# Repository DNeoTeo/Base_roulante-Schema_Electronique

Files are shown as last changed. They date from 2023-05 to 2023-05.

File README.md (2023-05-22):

# Base_roulante-Schema_Electronique

## Introduction

Dans le cadre du module Challenge, j’ai choisi de participer à la compétition de la coupe de France de Robotique 2023. Ce défi n’est pas envisageable tout seul. Avec des membres de l’association DTRE nous avons décidé de former une équipe. Ce « hackathon » nous a amené le défi de gérer et d’organiser une équipe de 29 personnes. À travers ce projet, j’ai pu travailler sur les différentes thématiques techniques telles que la programmation orienté objet, la mécanique ou encore l’électronique.

L’évènement a débuté le 10 septembre 2022 lors de la conférence de présentation de Planète Science organisé sur le campus d’EPITA. Ils y ont délivré la première version du règlement qui fut mis à jour quelques mois plus tard pour des questions d’homogénéités et pour clarifier certains points déséquilibré remontées par les équipes. Ce première évènement en début d’année nous a permis de poser toutes nos questions aux organisateurs et aux équipes vétéranes. Puisque nous sommes tous totalement novice de cette compétition. Le thème de cette année étant « The Cherry on the cake » pour fêter les 30 ans d’Eurobot, Planète Science demande aux équipes participant à la coupe de France de robotique de « cuisiner pour faire la fête ». 
Les missions fixées par le règlement de la 30ème édition sont : 

  − Fabriquer des gâteaux − Positionner la cerise sur les gâteaux   
  − Ranger le surplus des cerises dans le panier   
  − Se déguiser pour faire la fête. 
  
Sur le campus d’EPITA nous avons rencontré les organisateurs et des équipes habitués auprès desquelles nous avons pu prendre de précieux conseils.

Au début, Yasin, un membre de la DTRE et moi-même avons beaucoup travaillé en duo pour démarrer le projet puis nous avons délégué certaines parties aux membres qui ont rejoint l’équipe. J’ai ainsi participé à : 
  - Tous les entretiens des membres de l’équipe, 
  - La définition du budget (Annexe – Budget), 
  - La demande de subvention auprès de l’école ([Lien](https://docs.google.com/presentation/d/1tvP93IFA4L__9xUBjh1RfveQjmiez2jK/edit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)), 
  - Relecture du rapport PST de mi-année ([Lien](https://etesiea.sharepoint.com/:w:/r/sites/LesCavistes/Shared%20Documents/Rapport-PST/Rapport_PST_CDF_de_Robotique_2023.docx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)), 
  - Discussion avec les différents pôles pour connaître leur stratégie, 
  - Suivi de certains groupes pour s’assurer qu’ils n’avaient pas de problème à avancer, 
  - Récupération d’archive auprès d’une ancienne équipe ([Lien](https://etesiea.sharepoint.com/sites/LesCavistes/Shared%20Documents/Forms/AllItems.aspx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)) 
 
En plus de cette partie organisationnelle, je suis dans le pôle Base roulante spécialité électronique. J’ai ainsi réalisé plein de recherche pour le choix des composants de la base roulantes. 
Toutes les recherches sont dans le NoteBook suivant : [Elec – Base roulante](https://etesiea.sharepoint.com/:o:/r/sites/LesCavistes/_layouts/15/Doc.aspx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(Notes%20de%20R%C3%A9union%2FElec%20-%20Notes%20de%20r%C3%A9unions.one%7Cb93d645d-10fc-47ad-a43a-4c280d625987%2FElec%20%E2%80%93%20Base%20roulante%7Cc344ee84-79c5-4be7-819a-d46dd6609212%2F)&wdorigin=703&wdpreservelink=1) ([Web view](https://etesiea.sharepoint.com/:o:/r/sites/LesCavistes/_layouts/15/Doc.aspx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(Notes%20de%20R%C3%A9union%2FElec%20-%20Notes%20de%20r%C3%A9unions.one%7Cb93d645d-10fc-47ad-a43a-4c280d625987%2FElec%20%E2%80%93%20Base%20roulante%7Cc344ee84-79c5-4be7-819a-d46dd6609212%2F)&wdorigin=703&wdpreservelink=1)) Ce notebook est divisé en deux parties, à gauche la liste des composants adéquats pour toute la base roulante et ceux acheté pour le prototype n°1. Et à droite différentes parties théoriques et pistes de recherches pour bien choisir les composants. J’ai réalisé une chaîne fonctionnelle permet de visualiser l’ensemble de notre système : prise de décision avec la chaîne d’information, distribution de l’alimentation avec la chaîne d’énergie. On voit ainsi les composants nécessaires en fonction de leur rôle dans les 2 chaînes. Le diagramme électronique illustre la manière dont nos composants vont être reliés entre eux.

### La chaîne fonctionnelle



### Diagramme électrique



Premier prototype de la base roulante : https://drive.google.com/file/d/1hqDrjrIA7VDXRb-9ib1nsVt9VAf5gUXD/view?usp=share_link

En même que de mettre sur pieds, le prototype, j’ai commencé à faire les bibliothèques de composant sur eagle ainsi que les circuits imprimés. 

### Emergency_button (Board, Schematics et Librairy)







### Entrainement sur EAGLE

J’ai ainsi appris à créer des PCBs sur EAGLE avec la création de librairies ce qui inclut la création de schématics et de boards. Cette entrainement m’a permis de me familiariser avec les librairies de composants et l’IDE d’EAGLE.




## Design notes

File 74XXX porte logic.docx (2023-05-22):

74XXX porte logic

Sparkfun
Power symbol

Wurth

Con -> connectique

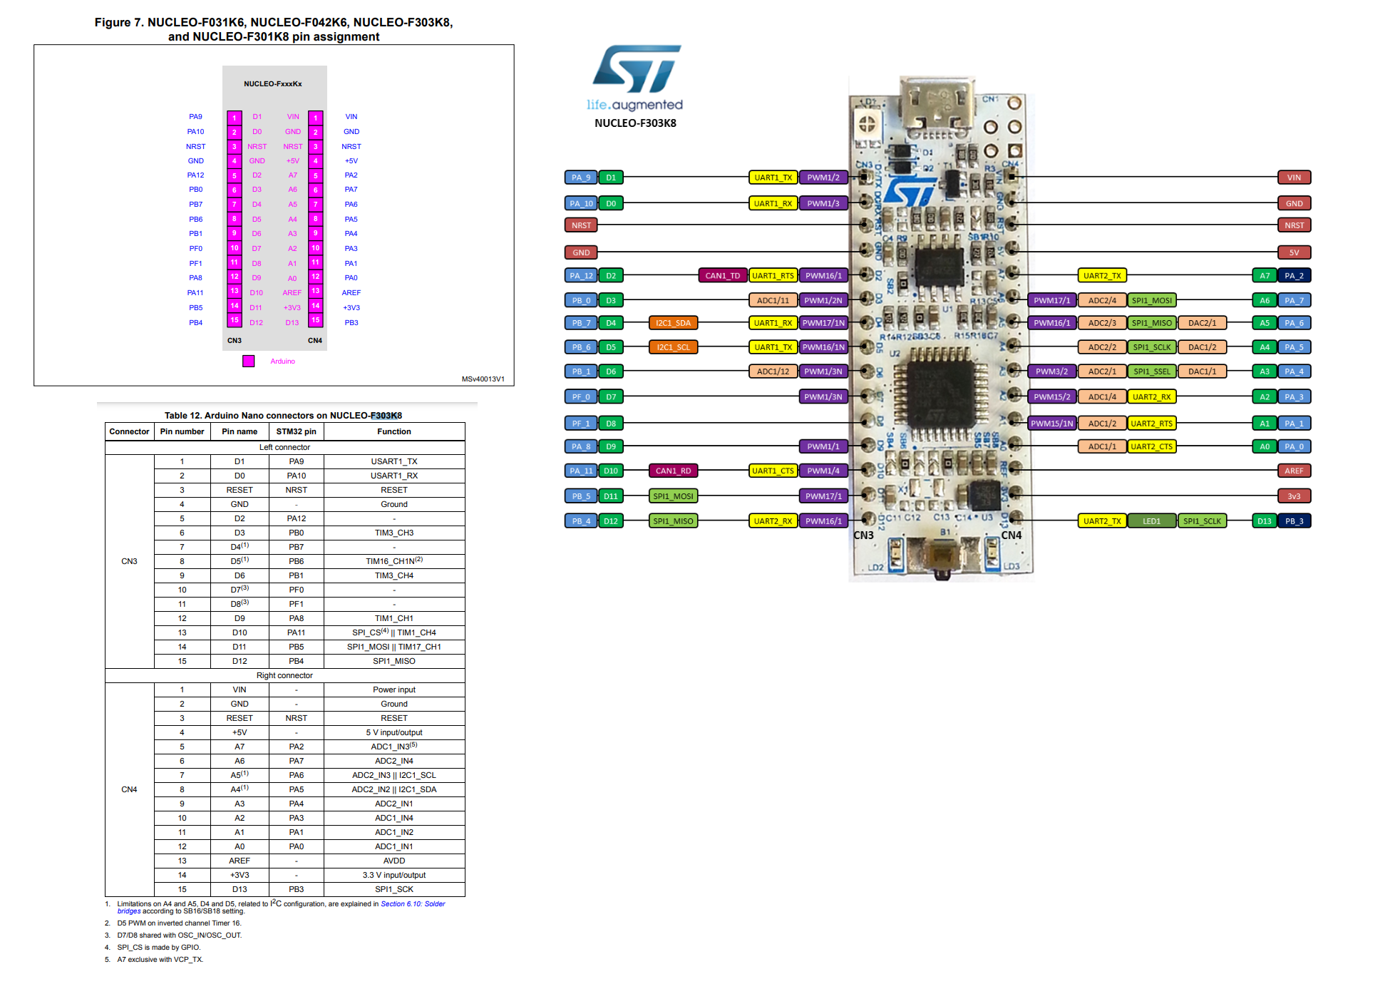
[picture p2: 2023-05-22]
PinMapping NUCLEO-F303K8.png

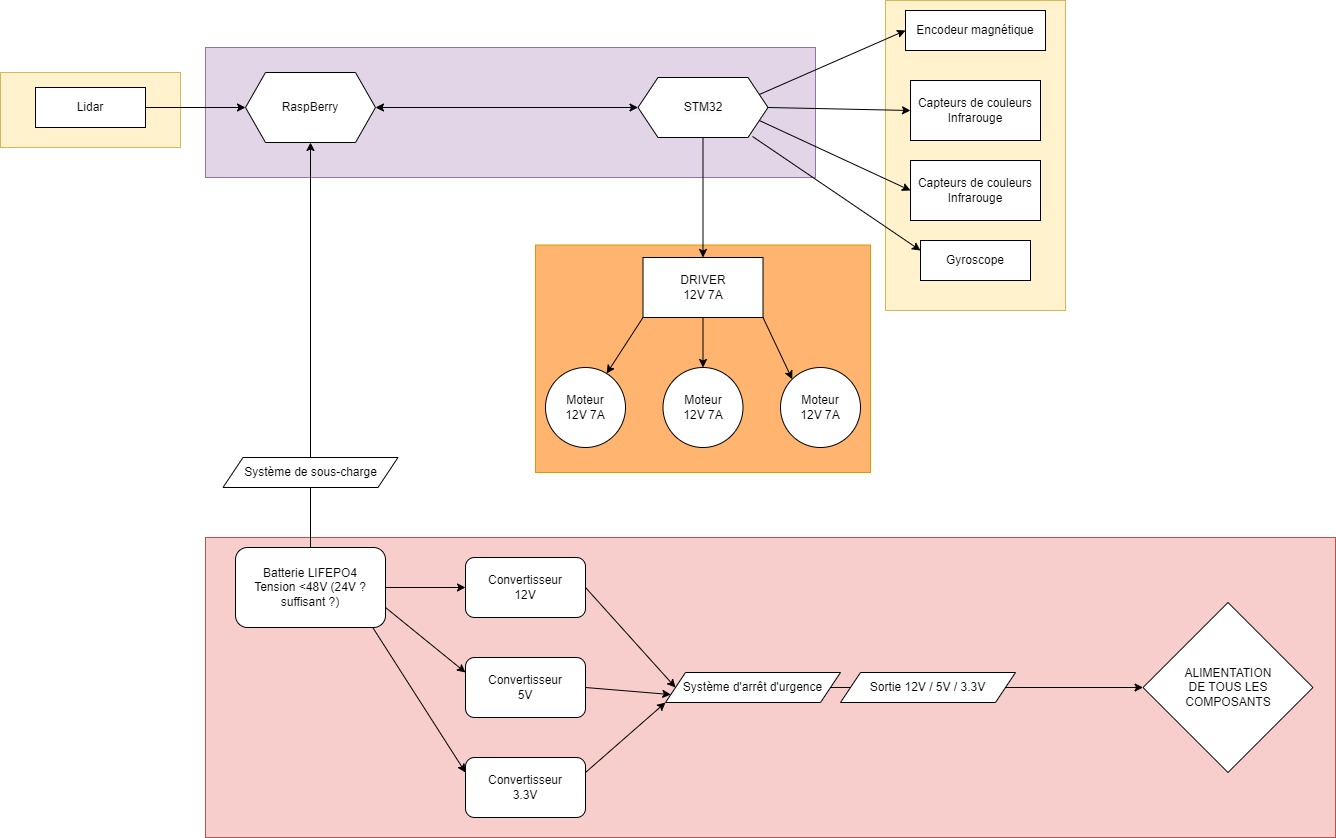
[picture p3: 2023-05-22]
Diagramme electrique.jpg

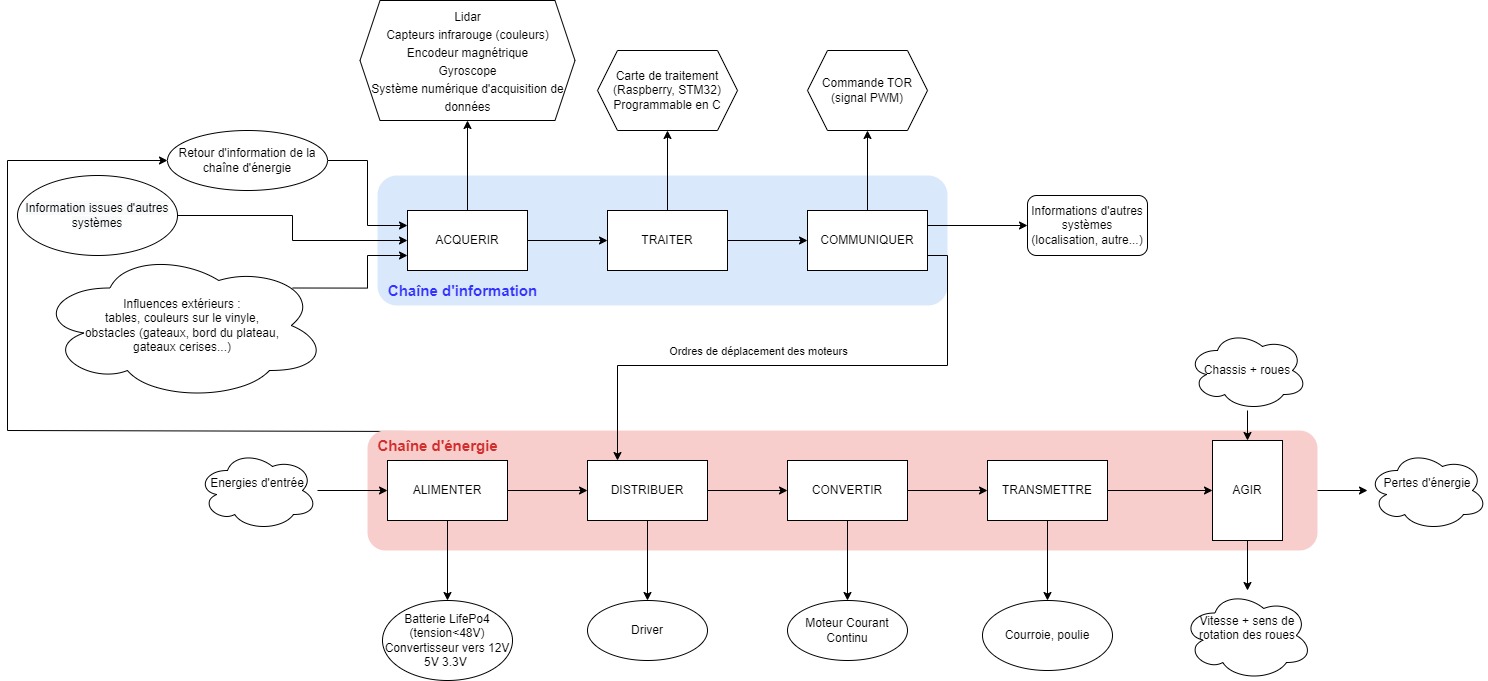
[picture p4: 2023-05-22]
Chaine fonct_energ.jpg

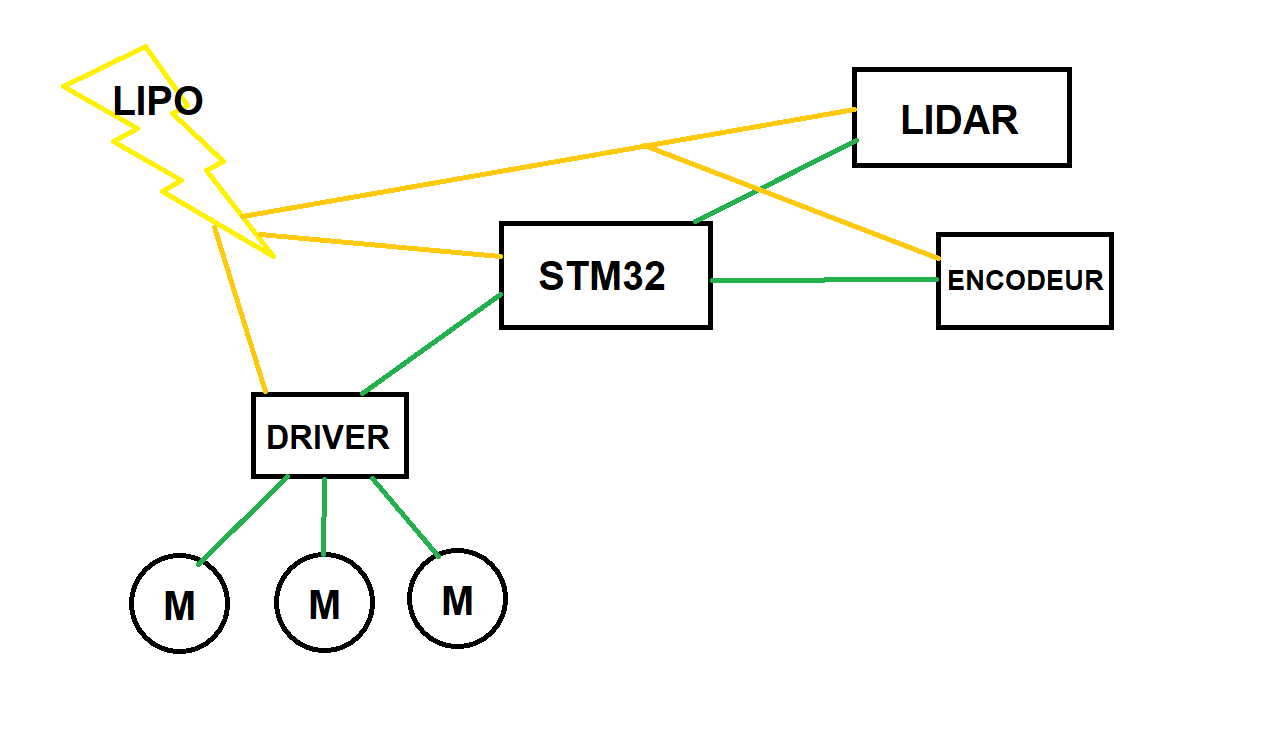
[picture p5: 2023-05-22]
Croquis Schema Elec Base roulante.png

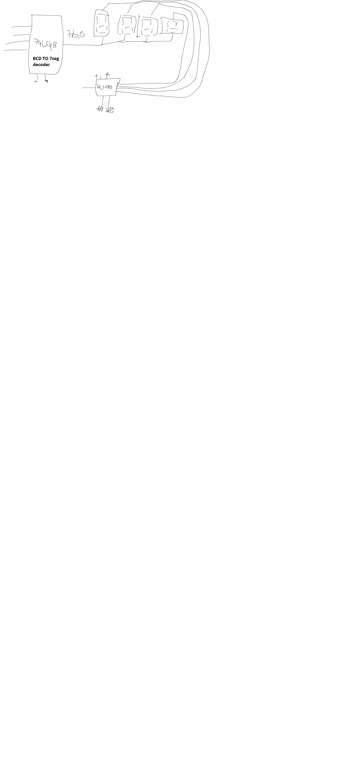
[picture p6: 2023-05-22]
projects/Eagle_train/horloge.png

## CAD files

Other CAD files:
22mm E-Stop v2.f3d

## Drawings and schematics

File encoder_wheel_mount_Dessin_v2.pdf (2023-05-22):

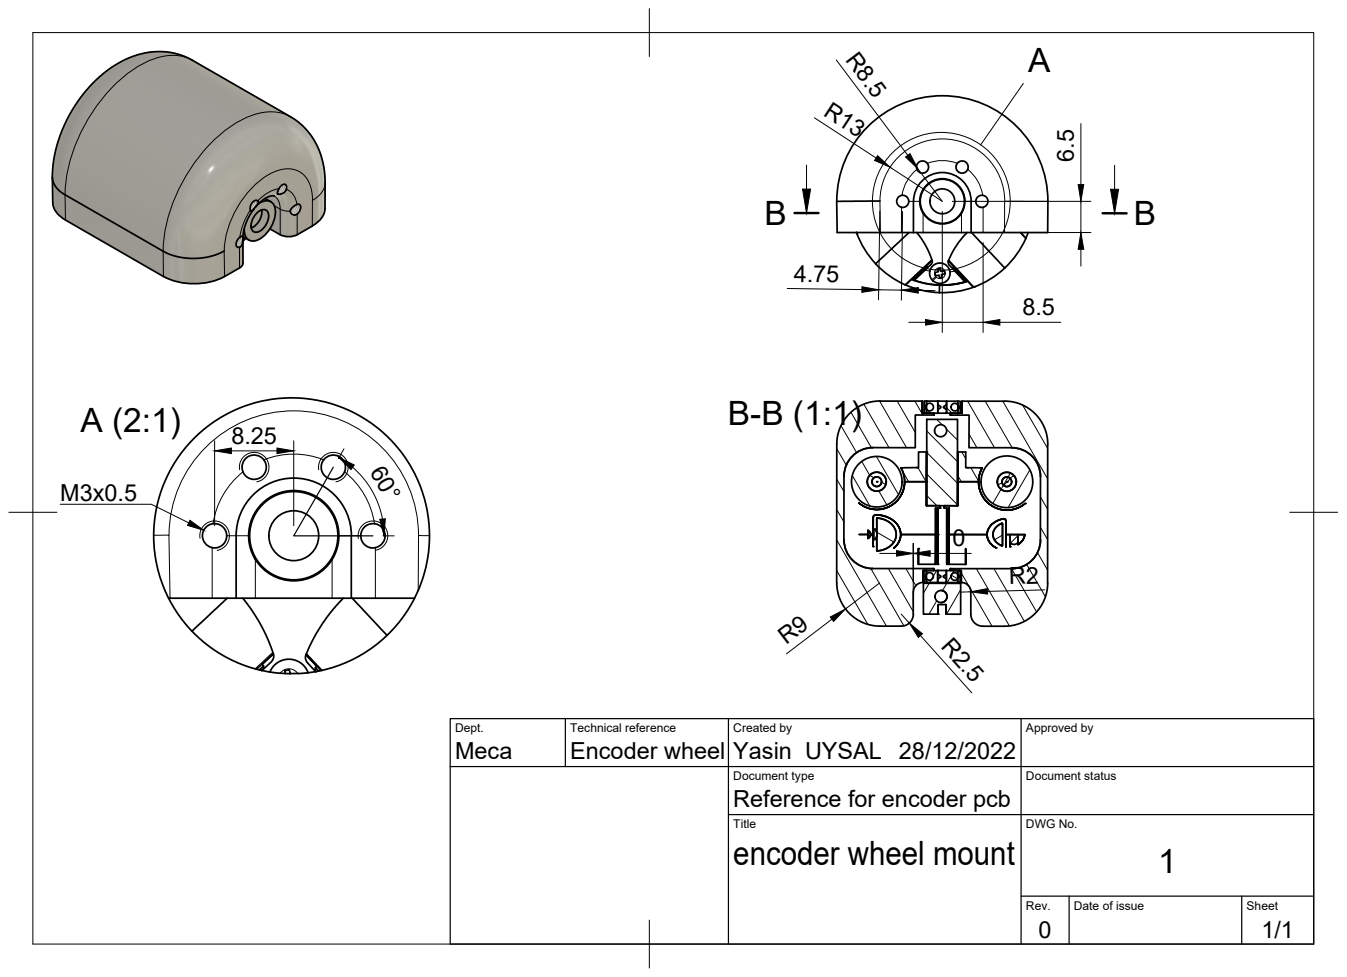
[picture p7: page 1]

Dept. Meca | Technical reference Encoder wheel | Created by Yasin UYSAL 28/12/2022 | Approved by

Document type Reference for encoder pcb | Document status

Title encoder wheel mount | DWG No. 1

Rev. 0 | Date of issue | Sheet 1/1

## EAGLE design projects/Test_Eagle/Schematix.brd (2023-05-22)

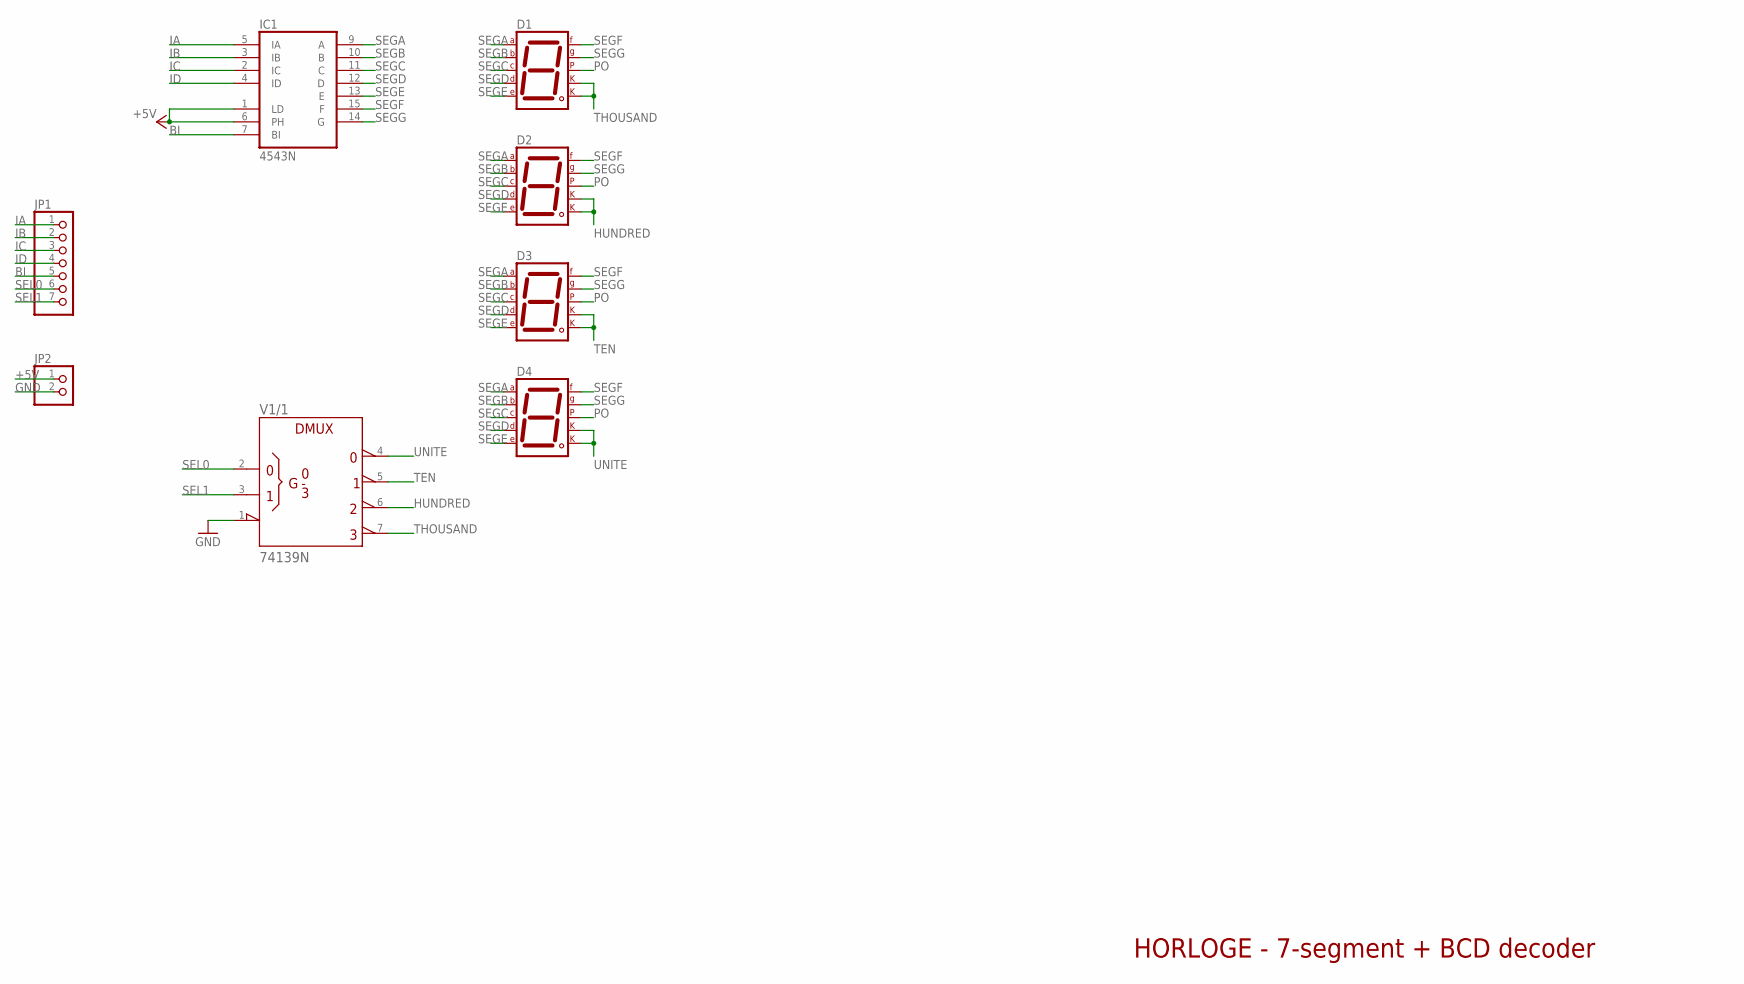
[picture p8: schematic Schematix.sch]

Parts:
D1, D2, D3, D4: 7SEG-CK; 7SEG-13
IC1: 4543N; DIL16
JP1: PINHD-1X7/90; 1X07/90
JP2: PINHD-1X2/90; 1X02/90
V1: 74139N; DIL16

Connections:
+5V: IC1.1 (LD), IC1.6 (PH), JP2.1
+UB: V1.16 (+UB)
-UB: V1.8 (-UB)
BI: IC1.7 (BI), JP1.5
GND: JP2.2, V1.1 (!G)
HUNDRED: D2.3 (CK1), D2.8 (CK2), V1.6 (Y2)
IA: IC1.5 (IA), JP1.1
IB: IC1.3 (IB), JP1.2
IC: IC1.2 (IC), JP1.3
ID: IC1.4 (ID), JP1.4
PO: D1.5 (DP), D2.5 (DP), D3.5 (DP), D4.5 (DP)
SEGA: D1.7 (A), D2.7 (A), D3.7 (A), D4.7 (A), IC1.9 (A)
SEGB: D1.6 (B), D2.6 (B), D3.6 (B), D4.6 (B), IC1.10 (B)
SEGC: D1.4 (C), D2.4 (C), D3.4 (C), D4.4 (C), IC1.11 (C)
SEGD: D1.2 (D), D2.2 (D), D3.2 (D), D4.2 (D), IC1.12 (D)
SEGE: D1.1 (E), D2.1 (E), D3.1 (E), D4.1 (E), IC1.13 (E)
SEGF: D1.9 (F), D2.9 (F), D3.9 (F), D4.9 (F), IC1.15 (F)
SEGG: D1.10 (G), D2.10 (G), D3.10 (G), D4.10 (G), IC1.14 (G)
SEL0: JP1.6, V1.2 (A)
SEL1: JP1.7, V1.3 (B)
TEN: D3.3 (CK1), D3.8 (CK2), V1.5 (Y1)
THOUSAND: D1.3 (CK1), D1.8 (CK2), V1.7 (Y3)
UNITE: D4.3 (CK1), D4.8 (CK2), V1.4 (Y0)
VDD: IC1.16 (VDD)
VSS: IC1.8 (VSS)

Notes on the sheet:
HORLOGE - 7-segment + BCD decoder

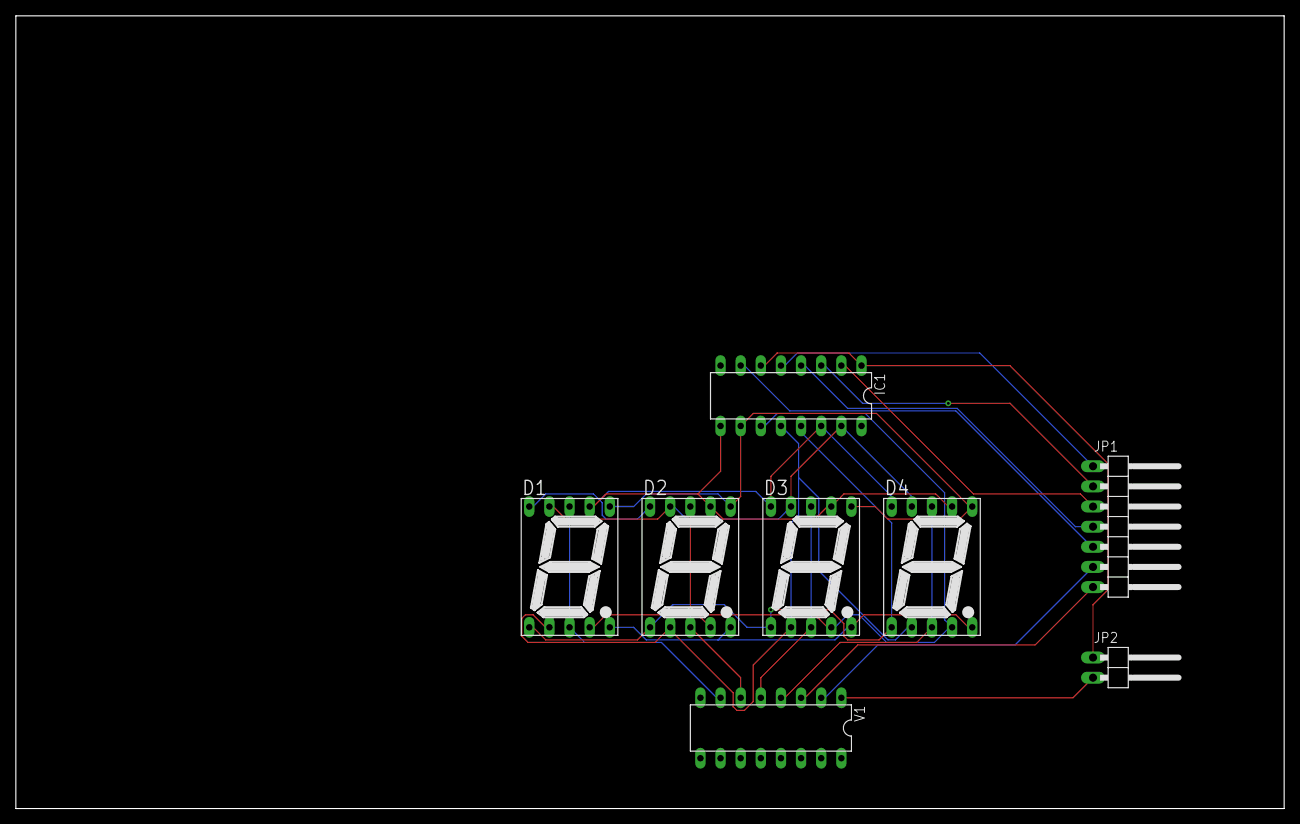
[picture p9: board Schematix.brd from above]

Board: 2 copper layers, 160.0 x 100.0 mm, 8 parts (0 on the bottom side), 21 nets.

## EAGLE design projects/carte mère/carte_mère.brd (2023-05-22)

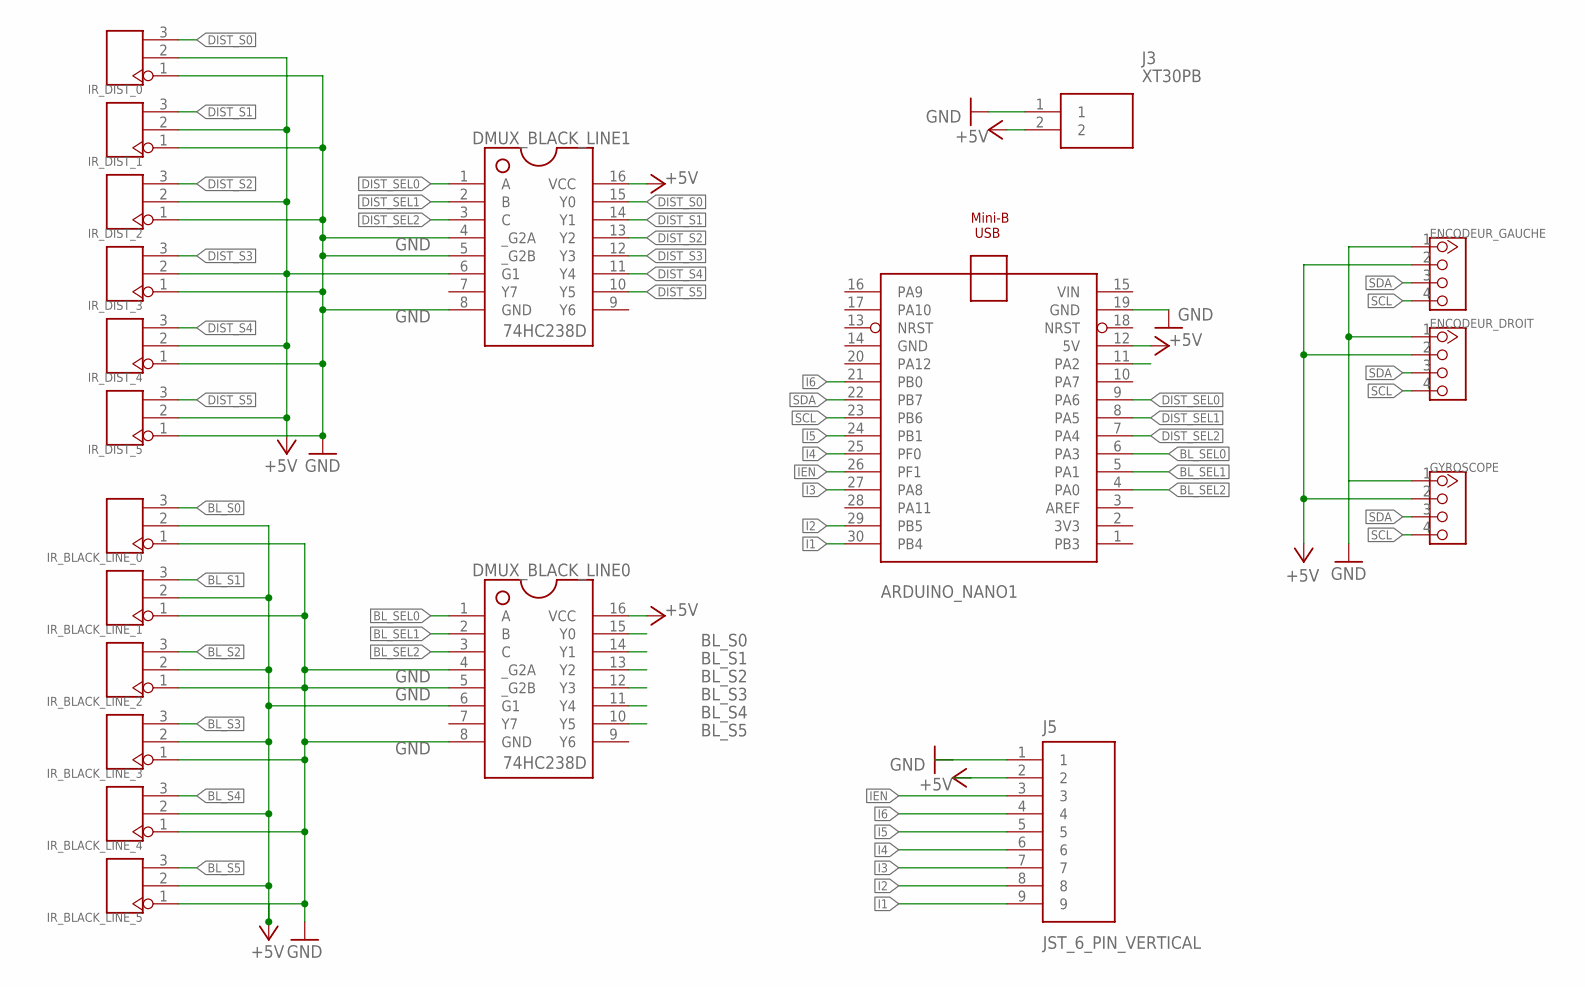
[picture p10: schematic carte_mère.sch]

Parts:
ARDUINO_NANO1: NUCLEO_F303K8
DMUX_BLACK_LINE0, DMUX_BLACK_LINE1: 74HC238D; SOIC127P600X175-16N
ENCODEUR_DROIT: TWIG-4P-2.0'90D'; 4P-2.0-90D
ENCODEUR_GAUCHE: TWIG-4P-2.0'90D'; 4P-2.0-90D
GYROSCOPE: TWIG-4P-2.0'90D'; 4P-2.0-90D
IR_BLACK_LINE_0, IR_BLACK_LINE_1, IR_BLACK_LINE_2, IR_BLACK_LINE_3, IR_BLACK_LINE_4, IR_BLACK_LINE_5: HEADER-3P-2.54; 3P-2.54
IR_DIST_0, IR_DIST_1, IR_DIST_2, IR_DIST_3, IR_DIST_4, IR_DIST_5: HEADER-3P-2.54; 3P-2.54
J3: XT30PB
J5: JST_6_PIN_VERTICAL; JST-6-SMD-VERT-1.0MM

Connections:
+5V: ARDUINO_NANO1.12 (5V), DMUX_BLACK_LINE0.6 (G1), DMUX_BLACK_LINE0.16 (VCC), DMUX_BLACK_LINE1.6 (G1), DMUX_BLACK_LINE1.16 (VCC), ENCODEUR_DROIT.2, ENCODEUR_GAUCHE.2, GYROSCOPE.2, IR_BLACK_LINE_0.2, IR_BLACK_LINE_1.2, IR_BLACK_LINE_2.2, IR_BLACK_LINE_3.2, IR_BLACK_LINE_4.2, IR_BLACK_LINE_5.2, IR_DIST_0.2, IR_DIST_1.2, IR_DIST_2.2, IR_DIST_3.2, IR_DIST_4.2, IR_DIST_5.2, J3.2, J5.2
BL_S0: DMUX_BLACK_LINE0.15 (Y0), IR_BLACK_LINE_0.3
BL_S1: DMUX_BLACK_LINE0.14 (Y1), IR_BLACK_LINE_1.3
BL_S2: DMUX_BLACK_LINE0.13 (Y2), IR_BLACK_LINE_2.3
BL_S3: DMUX_BLACK_LINE0.12 (Y3), IR_BLACK_LINE_3.3
BL_S4: DMUX_BLACK_LINE0.11 (Y4), IR_BLACK_LINE_4.3
BL_S5: DMUX_BLACK_LINE0.10 (Y5), IR_BLACK_LINE_5.3
BL_SEL0: ARDUINO_NANO1.6 (PA3), DMUX_BLACK_LINE0.1 (A)
BL_SEL1: ARDUINO_NANO1.5 (PA1), DMUX_BLACK_LINE0.2 (B)
BL_SEL2: ARDUINO_NANO1.4 (PA0), DMUX_BLACK_LINE0.3 (C)
DIST_S0: DMUX_BLACK_LINE1.15 (Y0), IR_DIST_0.3
DIST_S1: DMUX_BLACK_LINE1.14 (Y1), IR_DIST_1.3
DIST_S2: DMUX_BLACK_LINE1.13 (Y2), IR_DIST_2.3
DIST_S3: DMUX_BLACK_LINE1.12 (Y3), IR_DIST_3.3
DIST_S4: DMUX_BLACK_LINE1.11 (Y4), IR_DIST_4.3
DIST_S5: DMUX_BLACK_LINE1.10 (Y5), IR_DIST_5.3
DIST_SEL0: ARDUINO_NANO1.9 (PA6), DMUX_BLACK_LINE1.1 (A)
DIST_SEL1: ARDUINO_NANO1.8 (PA5), DMUX_BLACK_LINE1.2 (B)
DIST_SEL2: ARDUINO_NANO1.7 (PA4), DMUX_BLACK_LINE1.3 (C)
GND: ARDUINO_NANO1.14 (GND), ARDUINO_NANO1.19 (GND), DMUX_BLACK_LINE0.4 (_G2A), DMUX_BLACK_LINE0.5 (_G2B), DMUX_BLACK_LINE0.8 (GND), DMUX_BLACK_LINE1.4 (_G2A), DMUX_BLACK_LINE1.5 (_G2B), DMUX_BLACK_LINE1.8 (GND), ENCODEUR_DROIT.1, ENCODEUR_GAUCHE.1, GYROSCOPE.1, IR_BLACK_LINE_0.1, IR_BLACK_LINE_1.1, IR_BLACK_LINE_2.1, IR_BLACK_LINE_3.1, IR_BLACK_LINE_4.1, IR_BLACK_LINE_5.1, IR_DIST_0.1, IR_DIST_1.1, IR_DIST_2.1, IR_DIST_3.1, IR_DIST_4.1, IR_DIST_5.1, J3.1, J5.1
I1: ARDUINO_NANO1.30 (PB4), J5.9
I2: ARDUINO_NANO1.29 (PB5), J5.8
I3: ARDUINO_NANO1.27 (PA8), J5.7
I4: ARDUINO_NANO1.25 (PF0), J5.6
I5: ARDUINO_NANO1.24 (PB1), J5.5
I6: ARDUINO_NANO1.21 (PB0), J5.4
IEN: ARDUINO_NANO1.26 (PF1), J5.3
SCL: ARDUINO_NANO1.23 (PB6), ENCODEUR_DROIT.4, ENCODEUR_GAUCHE.4, GYROSCOPE.4
SDA: ARDUINO_NANO1.22 (PB7), ENCODEUR_DROIT.3, ENCODEUR_GAUCHE.3, GYROSCOPE.3
VIN: ARDUINO_NANO1.15 (VIN)

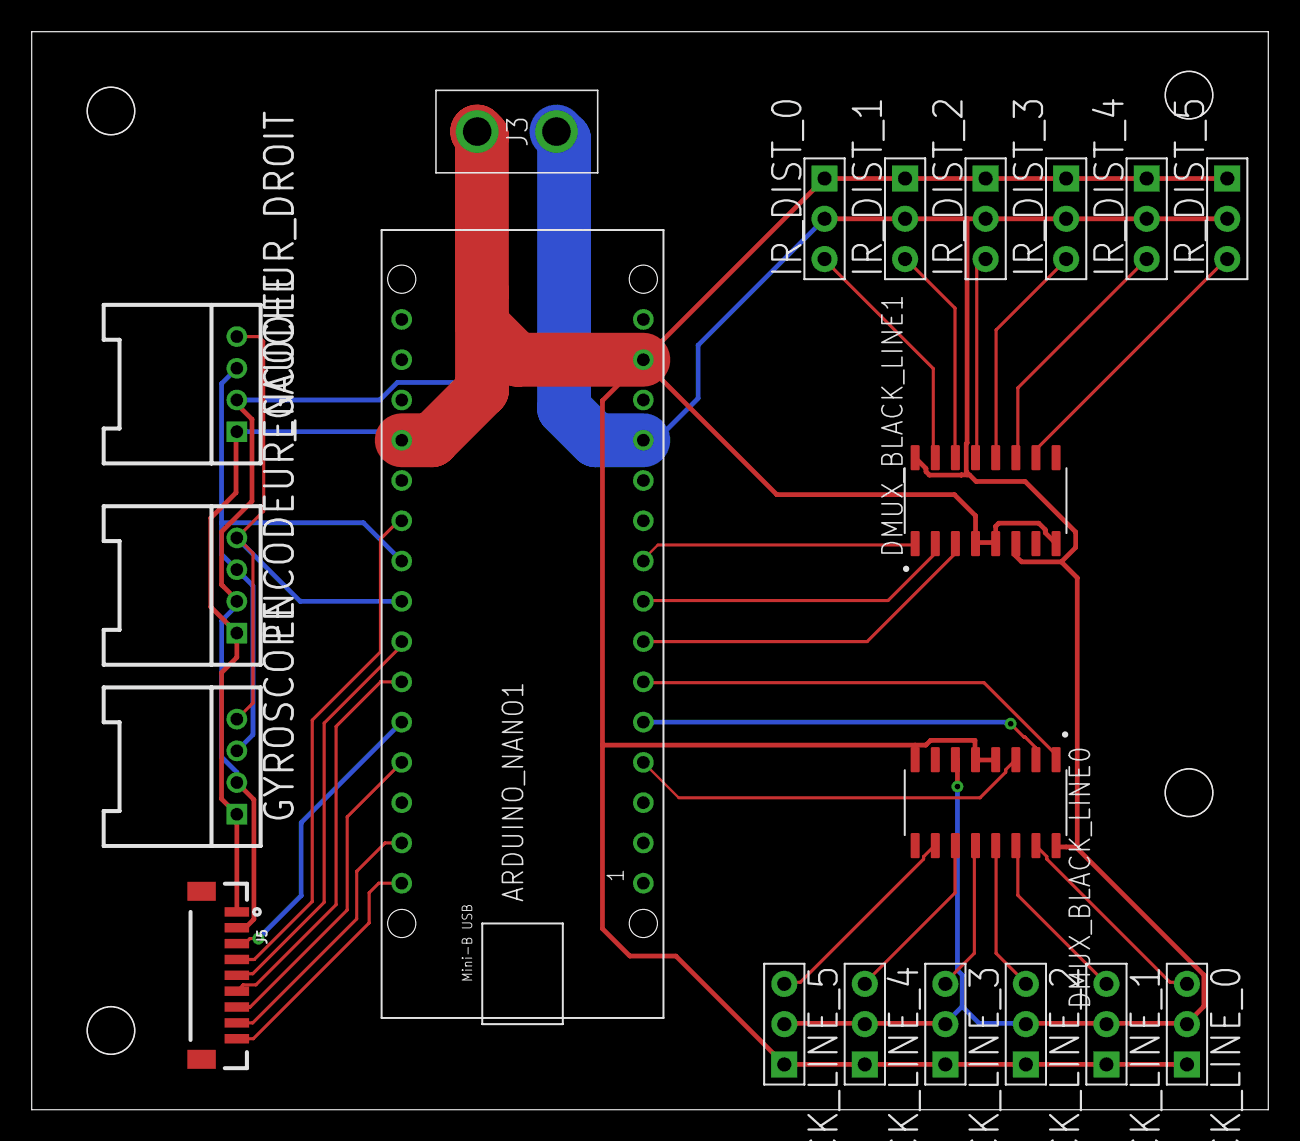
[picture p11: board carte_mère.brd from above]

Board: 2 copper layers, 78.0 x 68.0 mm, 20 parts (0 on the bottom side), 29 nets.

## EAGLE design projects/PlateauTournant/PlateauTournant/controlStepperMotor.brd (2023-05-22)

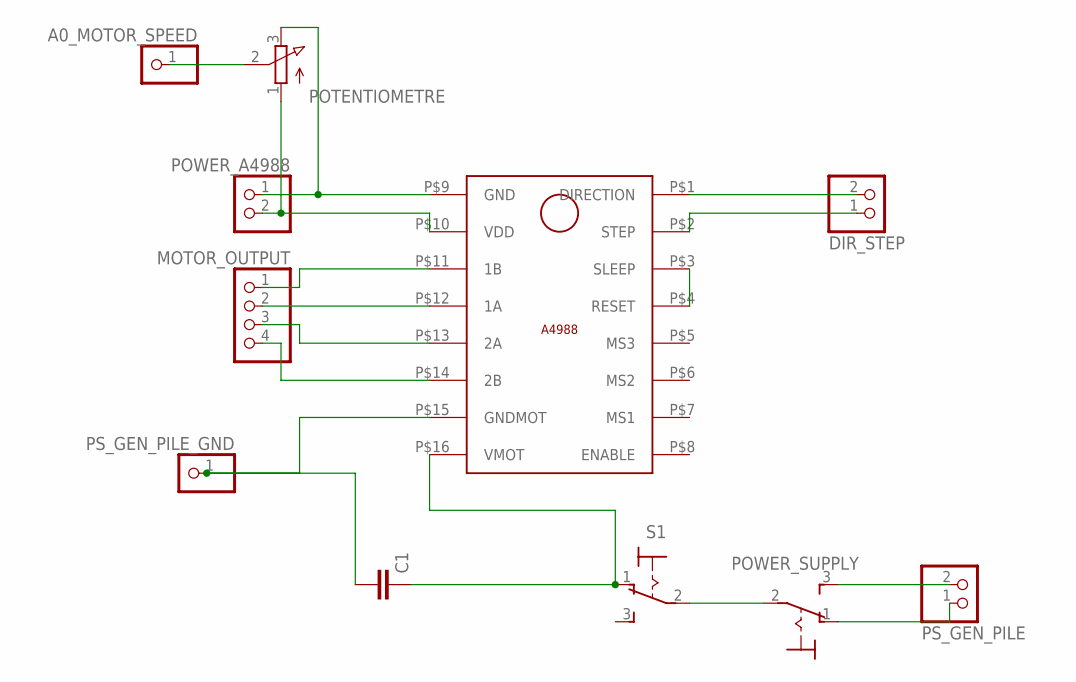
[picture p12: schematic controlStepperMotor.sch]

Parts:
A0_MOTOR_SPEED: PINHD-1X1; 1X01
C1: C2,5-3; C2.5-3
DIR_STEP: PINHD-1X2; 1X02
MOTOR_OUTPUT: PINHD-1X4; 1X04
POTENTIOMETRE: 3RP/1610N
POWER_A4988: PINHD-1X2; 1X02
POWER_SUPPLY: 320-916
PS_GEN_PILE: PINHD-1X2; 1X02
PS_GEN_PILE_GND: PINHD-1X1; 1X01
S1: M9040P
U$1: A4988-DRIVER-MOTOR

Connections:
unnamed: DIR_STEP.2, U$1.P$1 (DIRECTION)
unnamed: DIR_STEP.1, U$1.P$2 (STEP)
unnamed: POTENTIOMETRE.3 (E), POWER_A4988.1, U$1.P$9 (GND)
unnamed: POTENTIOMETRE.1 (A), POWER_A4988.2, U$1.P$10 (VDD)
unnamed: MOTOR_OUTPUT.1, U$1.P$11 (1B)
unnamed: MOTOR_OUTPUT.2, U$1.P$12 (1A)
unnamed: MOTOR_OUTPUT.3, U$1.P$13 (2A)
unnamed: MOTOR_OUTPUT.4, U$1.P$14 (2B)
unnamed: POWER_SUPPLY.2, S1.2
unnamed: C1.1, S1.1 (O), U$1.P$16 (VMOT)
unnamed: C1.2, PS_GEN_PILE_GND.1, U$1.P$15 (GNDMOT)
unnamed: POWER_SUPPLY.3 (S), PS_GEN_PILE.2
unnamed: POWER_SUPPLY.1 (O), PS_GEN_PILE.1
unnamed: A0_MOTOR_SPEED.1, POTENTIOMETRE.2 (S)

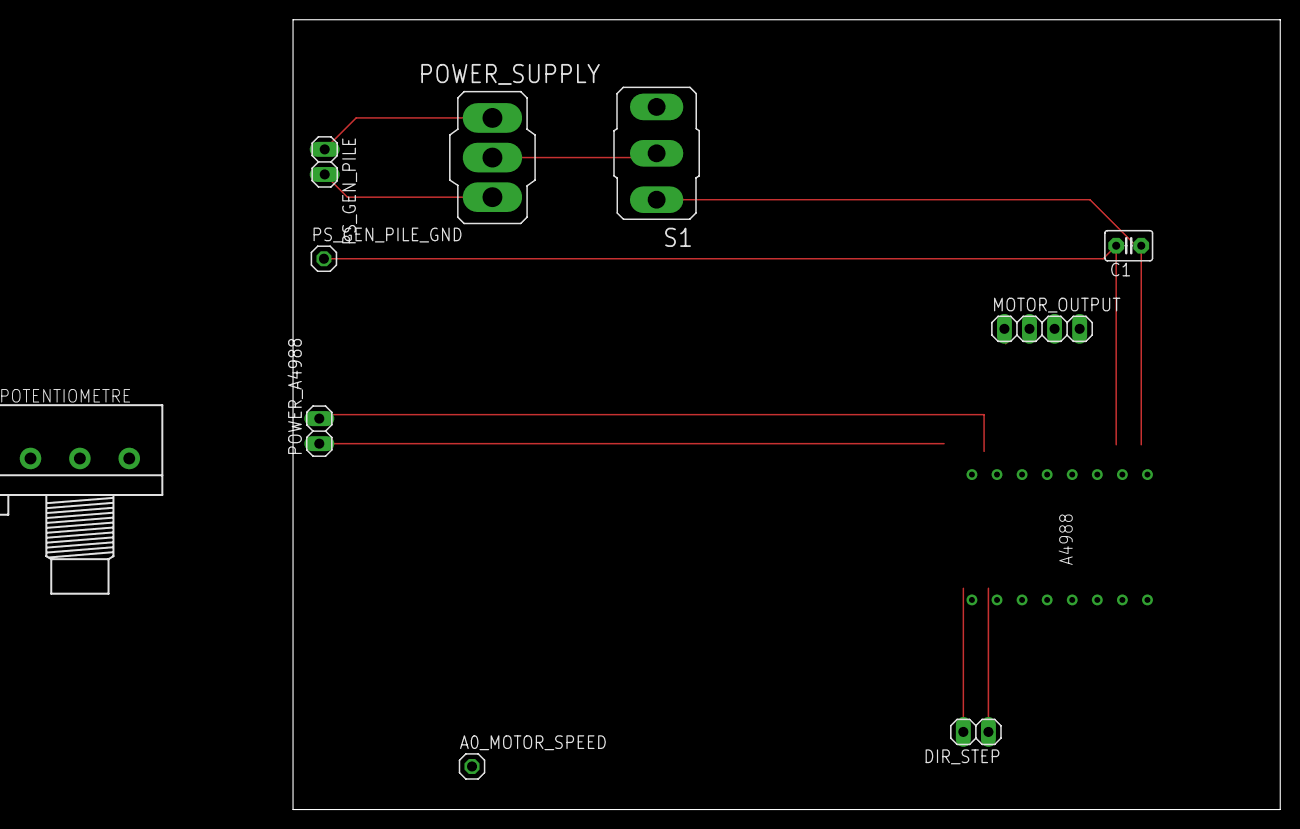
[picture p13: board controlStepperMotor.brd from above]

Board: 2 copper layers, 100.0 x 80.0 mm, 11 parts (0 on the bottom side), 14 nets.

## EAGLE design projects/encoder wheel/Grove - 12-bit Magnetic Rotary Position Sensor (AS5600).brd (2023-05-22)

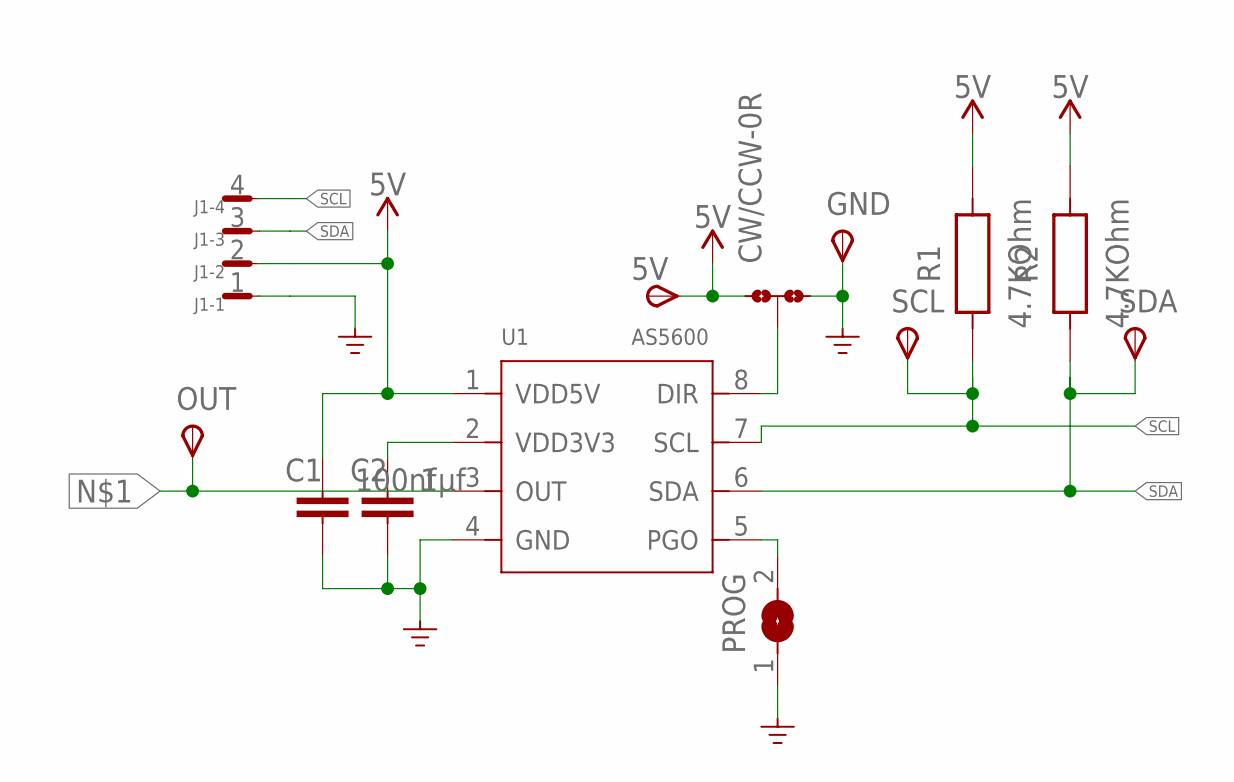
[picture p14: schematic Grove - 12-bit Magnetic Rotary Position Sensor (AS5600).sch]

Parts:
5V: TPSB2,54; B2,54
C1: 100nf; CAPC2012X110
C2: 1µf; CAPC2012X110
CW/CCW: 0R-JUMPA; A0R-JMP
GND: TPSB2,54; B2,54
J1: SM04B-SRSS-TB
OUT: TPSB2,54; B2,54
PROG: SJ
R1, R2: 4.7KOhm; WRIS-KSKE_0805_2.0X1.25X0.6(LXWXH)
SCL: TPSB2,54; B2,54
SDA: TPSB2,54; B2,54
U1: AS5600; SOIC8-1.27-5X4MM

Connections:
5V: 5V.TP, C1.1, CW/CCW.3, J1.2, R1.2, R2.2, U1.1 (VDD5V)
GND: C1.2, C2.2, CW/CCW.1, GND.TP, J1.1, PROG.1, U1.4 (GND)
unnamed: OUT.TP, U1.3 (OUT)
unnamed: CW/CCW.2, U1.8 (DIR)
unnamed: C2.1, U1.2 (VDD3V3)
unnamed: PROG.2, U1.5 (PGO)
SCL: J1.4, R1.1, SCL.TP, U1.7 (SCL)
SDA: J1.3, R2.1, SDA.TP, U1.6 (SDA)

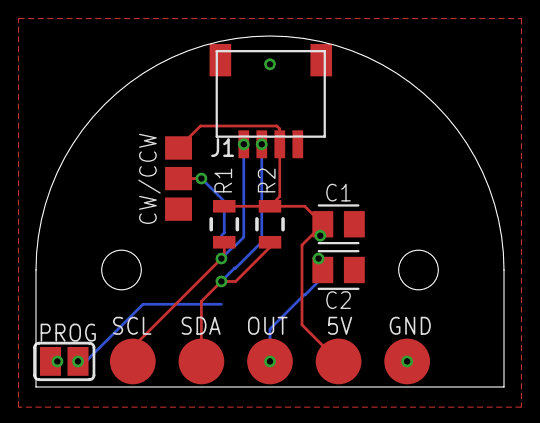
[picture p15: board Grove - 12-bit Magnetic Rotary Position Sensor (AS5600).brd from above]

Board: 2 copper layers, 26.0 x 19.5 mm, 13 parts (1 on the bottom side), 8 nets.

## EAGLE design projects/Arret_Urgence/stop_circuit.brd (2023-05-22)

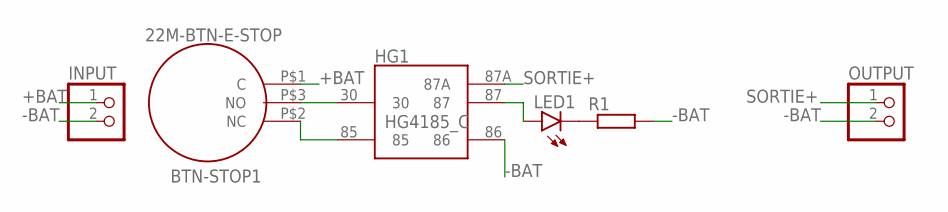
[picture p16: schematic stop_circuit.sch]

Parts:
BTN-STOP1: 22M-BTN-E-STOP; 22MM-BTN-E-STOP
HG1: HG4185_C; HG4185_C_1Z
INPUT: PINHD-1X2; 1X02
LED1: LEDB156; Q62902-B156
OUTPUT: PINHD-1X2; 1X02
R1: R-EU_0204/7; 0204/7

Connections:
+BAT: BTN-STOP1.P$1 (C), INPUT.1
-BAT: HG1.86, INPUT.2, OUTPUT.2, R1.2
unnamed: BTN-STOP1.P$3 (NO), HG1.30
unnamed: BTN-STOP1.P$2 (NC), HG1.85
unnamed: LED1.K (C), R1.1
unnamed: HG1.87, LED1.A
SORTIE+: HG1.87A, OUTPUT.1

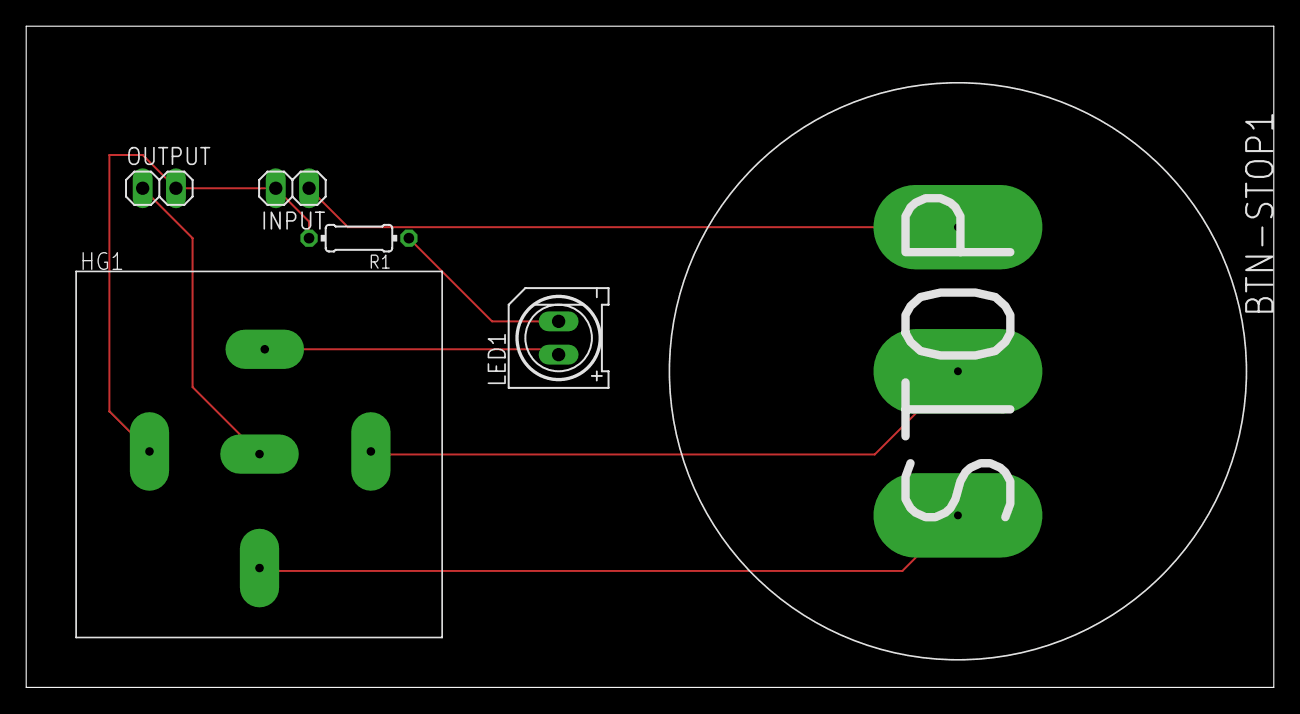
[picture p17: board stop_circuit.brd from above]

Board: 2 copper layers, 95.2 x 50.5 mm, 6 parts (0 on the bottom side), 7 nets.

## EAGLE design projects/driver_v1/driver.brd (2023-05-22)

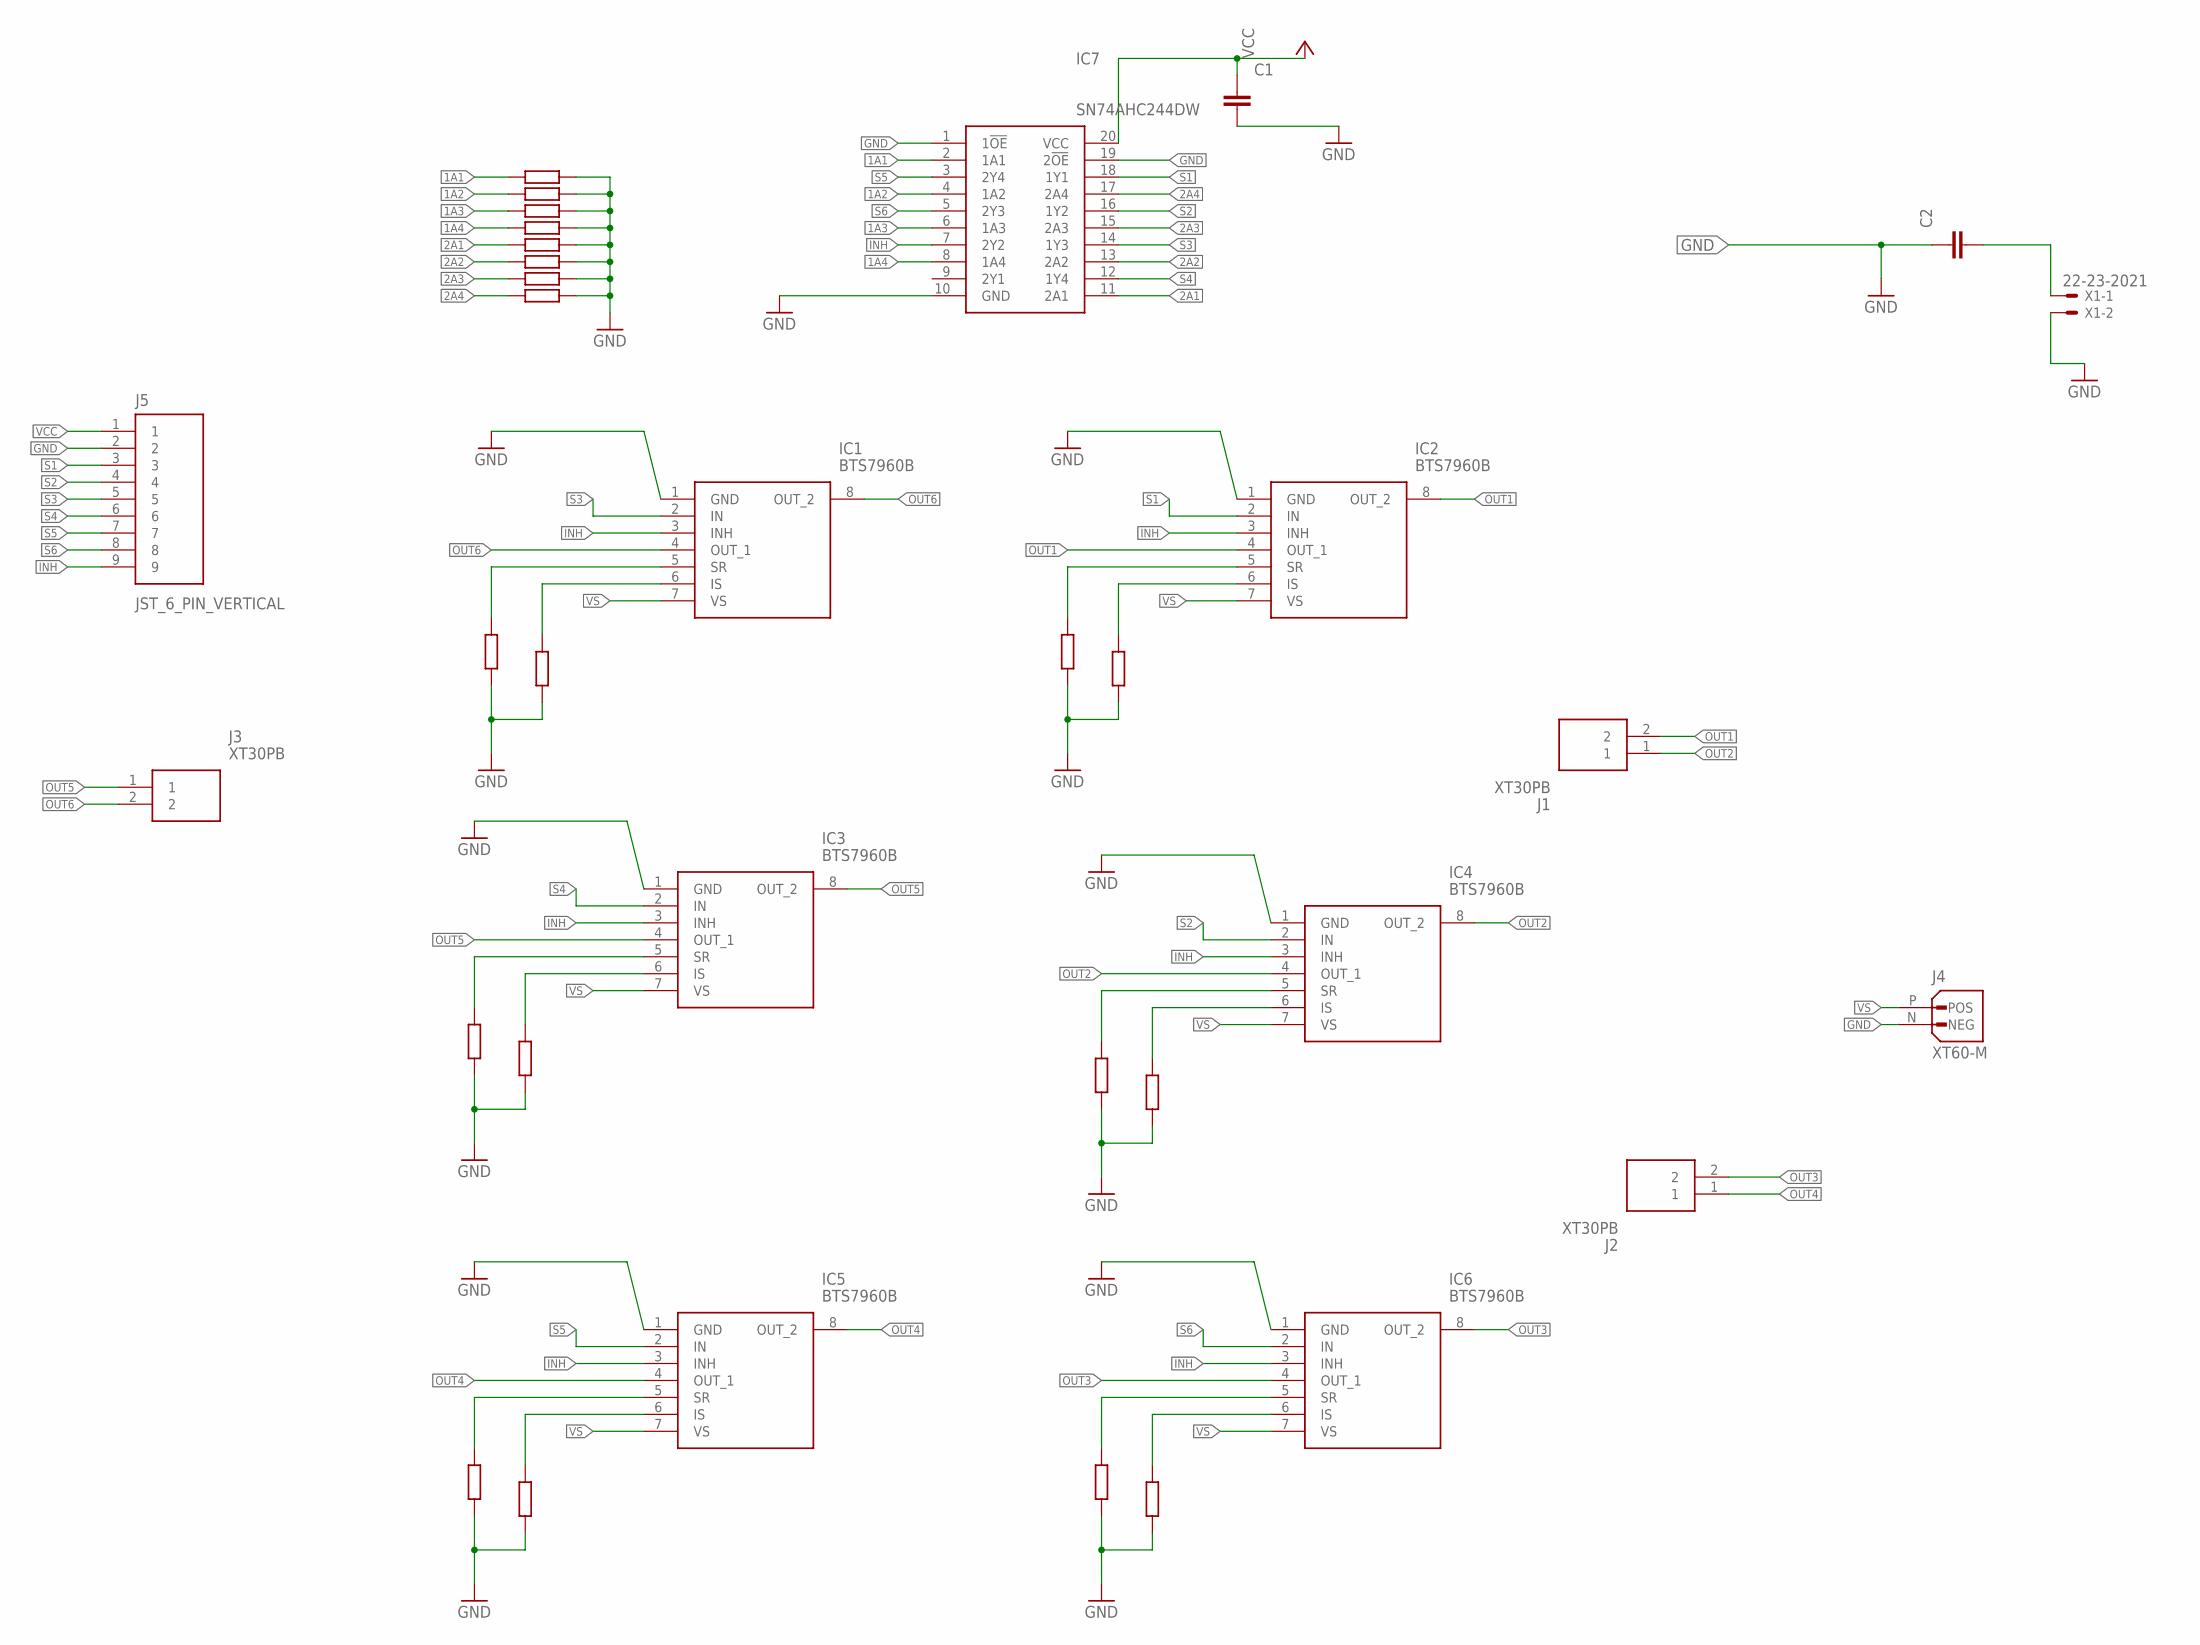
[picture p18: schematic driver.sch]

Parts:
IC1, IC2, IC3, IC4, IC5, IC6: BTS7960B
IC7: SN74AHC244DW; SOIC127P1030X265-20N
J1, J2, J3: XT30PB
J4: XT60-M; AMASS_XT60-M
J5: JST_6_PIN_VERTICAL; JST-6-SMD-VERT-1.0MM
X1: 22-23-2021

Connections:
2A4: IC7.17 (2A4)
GND: IC1.1 (GND), IC2.1 (GND), IC3.1 (GND), IC4.1 (GND), IC5.1 (GND), IC6.1 (GND), IC7.1 (1!OE), IC7.10 (GND), IC7.19 (2!OE), J4.N (NEG), J5.2, X1.2
INH: IC1.3 (INH), IC2.3 (INH), IC3.3 (INH), IC4.3 (INH), IC5.3 (INH), IC6.3 (INH), IC7.7 (2Y2), J5.9
OUT1: IC2.4 (OUT_1), IC2.8 (OUT_2), J1.2
OUT2: IC4.4 (OUT_1), IC4.8 (OUT_2), J1.1
OUT3: IC6.4 (OUT_1), IC6.8 (OUT_2), J2.2
OUT4: IC5.4 (OUT_1), IC5.8 (OUT_2), J2.1
OUT5: IC3.4 (OUT_1), IC3.8 (OUT_2), J3.1
OUT6: IC1.4 (OUT_1), IC1.8 (OUT_2), J3.2
S1: IC2.2 (IN), IC7.18 (1Y1), J5.3
S2: IC4.2 (IN), IC7.16 (1Y2), J5.4
S3: IC1.2 (IN), IC7.14 (1Y3), J5.5
S4: IC3.2 (IN), IC7.12 (1Y4), J5.6
S5: IC5.2 (IN), IC7.3 (2Y4), J5.7
S6: IC6.2 (IN), IC7.5 (2Y3), J5.8
VCC: IC7.20 (VCC), J5.1
VS: IC1.7 (VS), IC2.7 (VS), IC3.7 (VS), IC4.7 (VS), IC5.7 (VS), IC6.7 (VS), J4.P (POS)

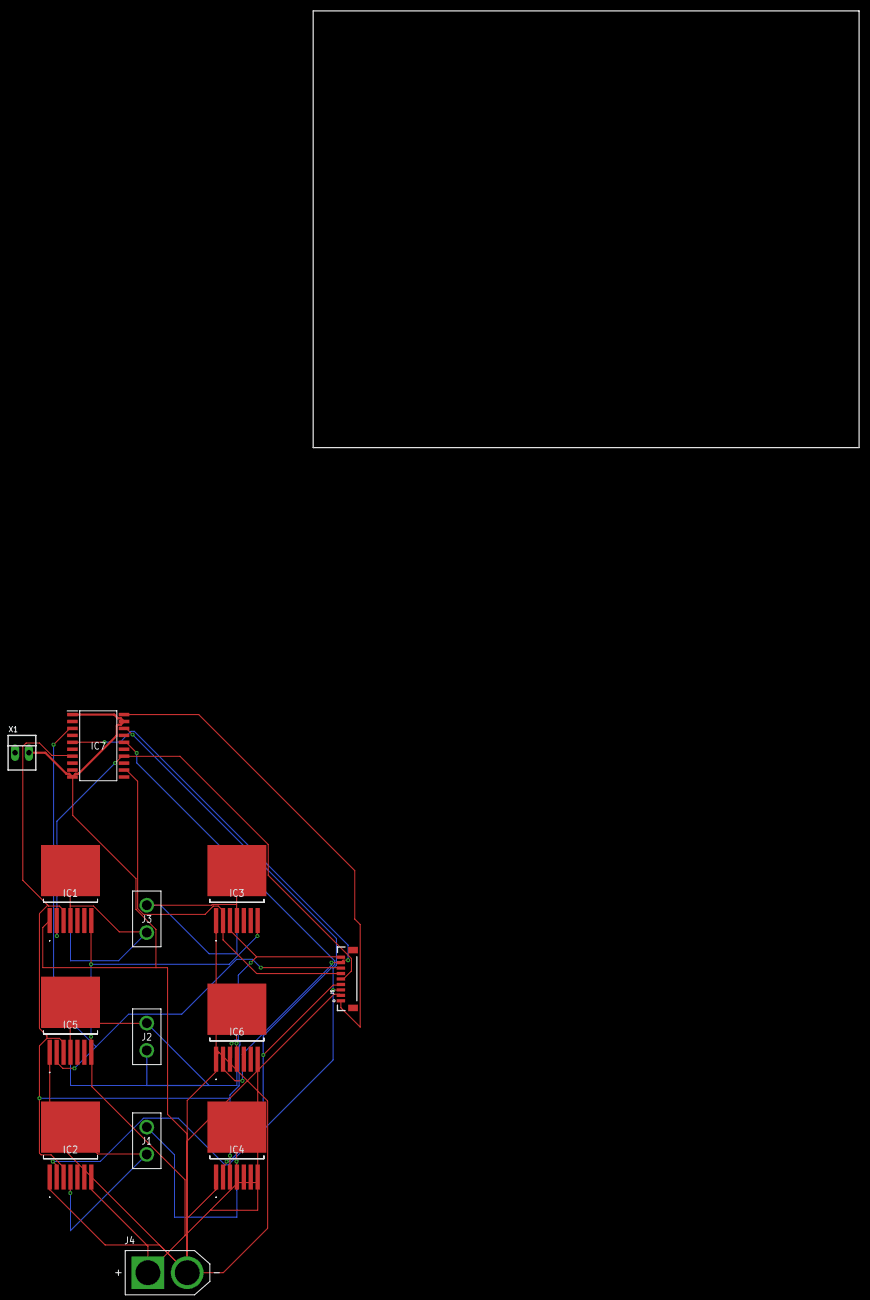
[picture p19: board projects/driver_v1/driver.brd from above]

Board: 2 copper layers, 100.0 x 80.0 mm, 13 parts (0 on the bottom side), 16 nets.

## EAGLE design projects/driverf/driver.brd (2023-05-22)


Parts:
C3: 100nF; WCAP-CSST_0805
C4, C5: 330 µF; WCAP-AS5H_10X10.5(DXL)
IC1, IC2, IC3, IC4, IC5, IC6: BTS7960B
IC7: SN74AHC244DW; SOIC127P1030X265-20N
J1, J2, J3: XT30PB
J4: XT60-M; AMASS_XT60-M
J5: JST_6_PIN_VERTICAL; JST-6-SMD-VERT-1.0MM
R1, R2, R3, R4, R5, R6, R7, R21, R22, R23, R24, R25, R26, R27, R28, R29, R36, R38, R39: 10k; WRIS-KSKE_0805_2.0X1.25X0.6(LXWXH)

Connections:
GND: C3.1, C4.2 (-), C5.2 (-), IC1.1 (GND), IC2.1 (GND), IC3.1 (GND), IC4.1 (GND), IC5.1 (GND), IC6.1 (GND), IC7.1 (1!OE), IC7.10 (GND), IC7.11 (2A1), IC7.19 (2!OE), J4.N (NEG), J5.1, R1.1, R2.1, R3.1, R4.1, R5.1, R6.1, R7.1, R21.1, R22.1, R23.1, R24.1, R25.1, R26.1, R27.1, R28.1, R29.1, R36.1, R38.1, R39.1
I1: IC7.2 (1A1), J5.9, R36.2
I2: IC7.4 (1A2), J5.8, R5.2
I3: IC7.6 (1A3), J5.7, R2.2
I4: IC7.8 (1A4), J5.6, R6.2
I5: IC7.13 (2A2), J5.5, R3.2
I6: IC7.15 (2A3), J5.4, R7.2
IEN: IC7.17 (2A4), J5.3, R4.2
unnamed: IC2.6 (IS), R1.2
unnamed: IC1.6 (IS), R38.2
unnamed: IC1.5 (SR), R39.2
unnamed: IC2.5 (SR), R21.2
unnamed: IC3.6 (IS), R24.2
unnamed: IC3.5 (SR), R25.2
unnamed: IC4.6 (IS), R23.2
unnamed: IC4.5 (SR), R22.2
unnamed: IC5.6 (IS), R26.2
unnamed: IC5.5 (SR), R27.2
unnamed: IC6.6 (IS), R29.2
unnamed: IC6.5 (SR), R28.2
OUT1: IC2.4 (OUT_1), IC2.8 (OUT_2), J1.2
OUT2: IC4.4 (OUT_1), IC4.8 (OUT_2), J1.1
OUT3: IC6.4 (OUT_1), IC6.8 (OUT_2), J2.2
OUT4: IC5.4 (OUT_1), IC5.8 (OUT_2), J2.1
OUT5: IC3.4 (OUT_1), IC3.8 (OUT_2), J3.1
OUT6: IC1.4 (OUT_1), IC1.8 (OUT_2), J3.2
S1: IC2.2 (IN), IC7.18 (1Y1)
S2: IC4.2 (IN), IC7.16 (1Y2)
S3: IC6.2 (IN), IC7.14 (1Y3)
S4: IC5.2 (IN), IC7.12 (1Y4)
S5: IC3.2 (IN), IC7.7 (2Y2)
S6: IC1.2 (IN), IC7.5 (2Y3)
SEN: IC1.3 (INH), IC2.3 (INH), IC3.3 (INH), IC4.3 (INH), IC5.3 (INH), IC6.3 (INH), IC7.3 (2Y4)
VCC: C3.2, IC7.20 (VCC), J5.2
VS: C4.1 (+), C5.1 (+), IC1.7 (VS), IC2.7 (VS), IC3.7 (VS), IC4.7 (VS), IC5.7 (VS), IC6.7 (VS), J4.P (POS)


Board: 2 copper layers, 78.6 x 73.7 mm, 34 parts (0 on the bottom side), 35 nets.

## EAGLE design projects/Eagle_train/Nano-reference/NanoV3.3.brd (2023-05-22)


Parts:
C1, C4, C6, C9: 100nF; C0603-ROUND
C2, C5: 4,7uF_16V; TAN-A
C3, C7, C8: 1uF; C0603-ROUND
D1: SS1P3L; DO220AAL
D+: DNP; TP-1.00MM
D-: DNP; TP-1.00MM
F1: MFFSMF050; 0603-1608X90N
FRAME1: DNP; FRAME
IC1: FT232RL; SSOP28
IC2: LM1117IMPX-5.0; LINEAR_SOT223
IC3: 328P-MUR; VQFN32
J1, J2: XXXX_STRIPNANO; HEAD15-NOSS
J3: 0219_14850; USB-MINI-B_2
J4: 0114_PH254-203DF118A00V; 2X03
L: Yellow; CHIPLED_0805
PWR: Green; CHIPLED_0805
RP1, RP2: 1K; CAY16
RX: Red; CHIPLED_0805
SW1: RESET; SMD_157SW
TX: Green; CHIPLED_0805
U$4, U$5, U$53, U$54: DNP; FD-1-1.5
Y1: 16MHz; RESONATOR

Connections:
3V3: C6.2, IC1.17 (3V3OUT), J2.14
+5V: C3.1, C5.1 (+), C7.1, C8.1, D1.P$1 (K), IC1.4 (VCCIO), IC1.20 (VCC), IC2.2 (OUT), IC2.4 (OUT), IC3.4 (VCC), IC3.6 (VCC), IC3.18 (AVCC), J2.4, J4.2, RP1.5 (2), RP1.6 (2), RX.A, TX.A
A0: IC3.23 (PC0(ADC0)), J2.12
A1: IC3.24 (PC1(ADC1)), J2.11
A2: IC3.25 (PC2(ADC2)), J2.10
A3: IC3.26 (PC3(ADC3)), J2.9
A4: IC3.27 (PC4(ADC4/SDA)), J2.8
A5: IC3.28 (PC5(ADC5/SCL)), J2.7
A6: IC3.19 (ADC6), J2.6
A7: IC3.22 (ADC7), J2.5
AREF: C1.1, IC3.20 (AREF), J2.13
COM: C1.2, C2.2 (-), C3.2, C5.2 (-), C6.1, C7.2, C8.2, C9.2, IC1.7 (GND1), IC1.18 (GND2), IC1.21 (GND3), IC1.25 (AGND), IC1.26 (TEST), IC2.1 (GND/ADJ), IC3.3 (GND), IC3.5 (GND), IC3.21 (AGND), IC3.33 (GND), J1.4, J2.2, J3.1 (GND), J3.6 (SH1), J3.7 (SH2), J3.8 (SH3), J3.9 (SH4), J4.6, L.C, PWR.C, RP2.3 (1), RP2.6 (2), SW1.1, Y1.2
D0/RX: IC3.30 (PD0(RXD)), J1.2, RP1.1
D1/TX: IC3.31 (PD1(TXD)), J1.1, RP1.2 (1)
D2: IC3.32 (PD2(INT0)), J1.5
D3: IC3.1 (PD3(INT1)), J1.6
D4: IC3.2 (PD4(XCK/T0)), J1.7
D5: IC3.9 (PD5(T1)), J1.8
D6: IC3.10 (PD6(AIN0)), J1.9
D7: IC3.11 (PD7(AIN1)), J1.10
D8: IC3.12 (PB0(ICP)), J1.11
D9: IC3.13 (PB1(OC1A)), J1.12
D10: IC3.14 (PB2(SS/OC1B)), J1.13
D11/MOSI: IC3.15 (PB3(MOSI/OC2)), J1.14, J4.4
D12/MISO: IC3.16 (PB4(MISO)), J1.15, J4.1
D13/SCK: IC3.17 (PB5(SCK)), J2.15, J4.3, RP2.1
unnamed: IC3.8 (PB7(XTAL2/TOSC2)), Y1.3
unnamed: IC3.7 (PB6(XTAL1/TOSC1)), Y1.1
unnamed: PWR.A, RP1.3 (1)
unnamed: C4.2, IC1.2 (DTR#)
unnamed: D+.X, IC1.15 (USBDP), J3.3 (D+)
unnamed: D-.X, IC1.16 (USBDM), J3.4 (D-)
unnamed: L.A, RP2.8 (2)
unnamed: IC1.23 (CBUS0), RP2.2 (1)
unnamed: IC1.22 (CBUS1), RP2.4 (1)
unnamed: RP2.5 (2), TX.C
unnamed: F1.2, J3.5 (VBUS)
unnamed: RP2.7 (2), RX.C
RESET: C4.1, IC3.29 (PC6(/RESET)), J1.3, J2.3, J4.5, RP1.4 (1), SW1.2
RX: IC1.1 (TXD), RP1.8 (2)
TX: IC1.5 (RXD), RP1.7 (2)
VIN: IC2.3 (IN), J2.1
VUSB: C2.1 (+), C9.1, D1.P$2 (A), F1.1

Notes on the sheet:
+5V REG
ICSP
USB
+5V AUTO SELECTOR
Arturo Guadalupi



Board: 2 copper layers, 43.2 x 17.8 mm, 33 parts (17 on the bottom side), 43 nets.

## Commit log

2023-03-08 New circuit
    [RASSEMBLEMENT_BR.sch]
2023-05-22 Ajout des circuits imprimés EAGLE, d'entrainemet mais aussi les circuits finaux de la base roulante de la CDFR
    [22mm E-Stop v2.f3d, Base roulante v1.sch, Grove - 12-bit Magnetic Rotary Position Sensor (AS5600).brd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]

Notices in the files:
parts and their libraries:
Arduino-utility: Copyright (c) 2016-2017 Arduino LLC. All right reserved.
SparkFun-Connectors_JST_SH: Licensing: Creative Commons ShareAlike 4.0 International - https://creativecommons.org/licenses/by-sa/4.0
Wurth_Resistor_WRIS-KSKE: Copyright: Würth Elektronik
